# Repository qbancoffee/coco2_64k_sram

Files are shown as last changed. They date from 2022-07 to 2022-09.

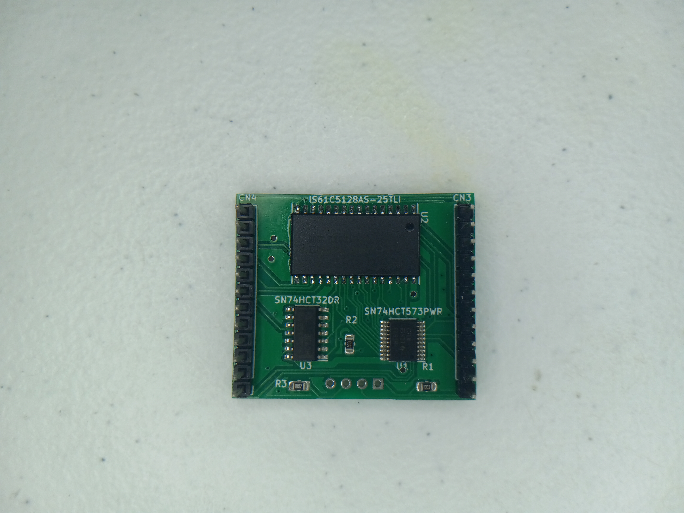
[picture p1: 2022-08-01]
images/board_bottom.jpg

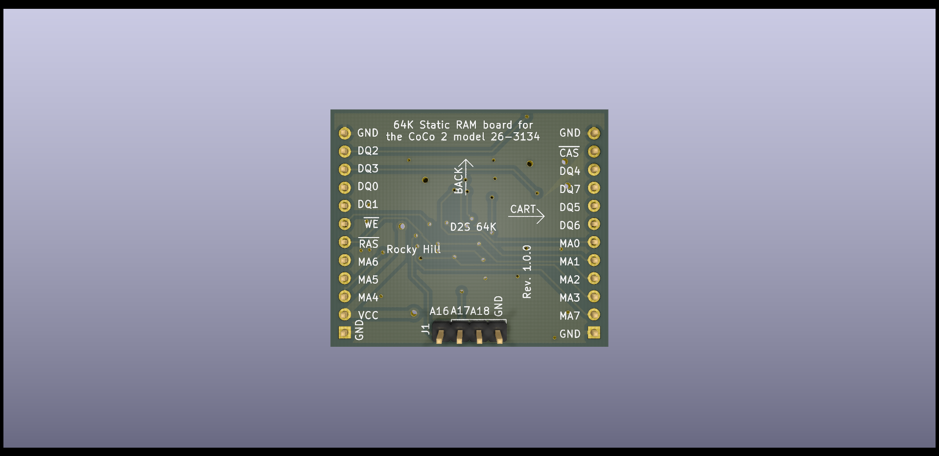
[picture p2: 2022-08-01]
images/board_top_rendered.png

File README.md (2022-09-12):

# coco2_64k_sram
Static RAM board for the Tandy Color Computer 2 model 26-3134

This KiCAD project includes the schematic and PCB design for a 64k static RAM board for the
Tandy Color Computer 2 model 26-3134. It is designed to plug into the expansion port.
There are two versions of the board in this repo, the main one which is the SMD version
and there is a through hole version under "coco2_3134_64k_static_ram_board_tht".

## Credits
The design for this board was inspired by the following.
- [Ciaran Ascomb's 512K static RAM board for the CoCo 3.](https://gitlab.com/sixxie/cc3-512k)
- [Jamaru's static RAM board for for the Commodore 64, based on Garrit4's design](https://github.com/jamarju/c64-sram)
- [Garrit4's SRAM board design.](https://www.lemon64.com/forum/viewtopic.php?p=773935#773935)

## Docs
- [Schematic](https://github.com/qbancoffee/coco2_64k_sram/blob/main/pdfs/schematic.pdf)
- [Rendered Image top](https://github.com/qbancoffee/coco2_64k_sram/blob/main/images/board_top_rendered.png)
- [Rendered Image bottom](https://github.com/qbancoffee/coco2_64k_sram/blob/main/images/board_bottom_rendered.png)
- [Board top](https://github.com/qbancoffee/coco2_64k_sram/blob/main/images/board_top.jpg)
- [Board bottom](https://github.com/qbancoffee/coco2_64k_sram/blob/main/images/board_bottom.jpg)
- [Board installed](https://github.com/qbancoffee/coco2_64k_sram/blob/main/images/board_installed.jpg)
- [Interactive BOM](https://htmlpreview.github.io/?https://github.com/qbancoffee/coco2_64k_sram/blob/main/bom/ibom.html)
- [Interactive BOM for the through hole version](https://htmlpreview.github.io/?https://github.com/qbancoffee/coco2_64k_sram/blob/main/bom/ibom_tht.html)
- [Bill Of Materials (BOM)](https://github.com/qbancoffee/coco2_64k_sram/blob/main/bom/bom.csv)
- [Bill Of Materials for the through hole version (BOM)](https://github.com/qbancoffee/coco2_64k_sram/blob/main/bom/bom_tht.csv)

## Videos
- [Installing the board in a CoCo 2](https://youtu.be/qNmRELRTp34)
- [Making a through hole version of the board](https://youtu.be/qkUWCKWGy-E)

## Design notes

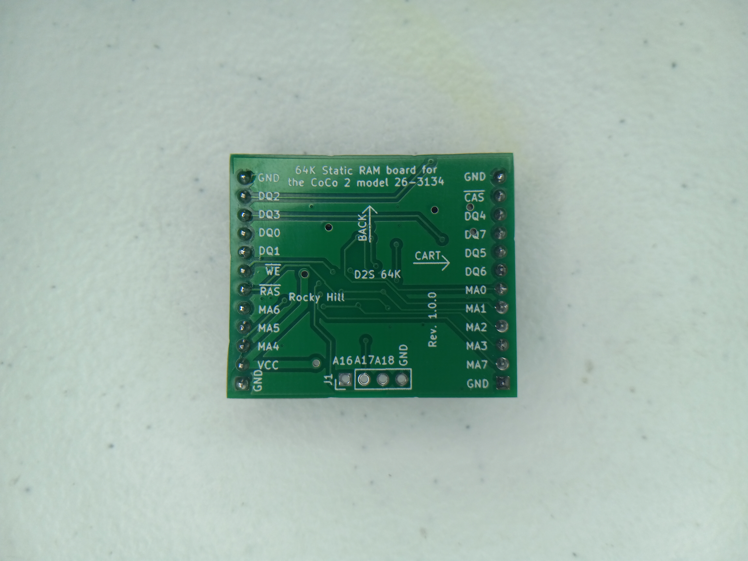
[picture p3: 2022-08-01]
images/board_top.jpg

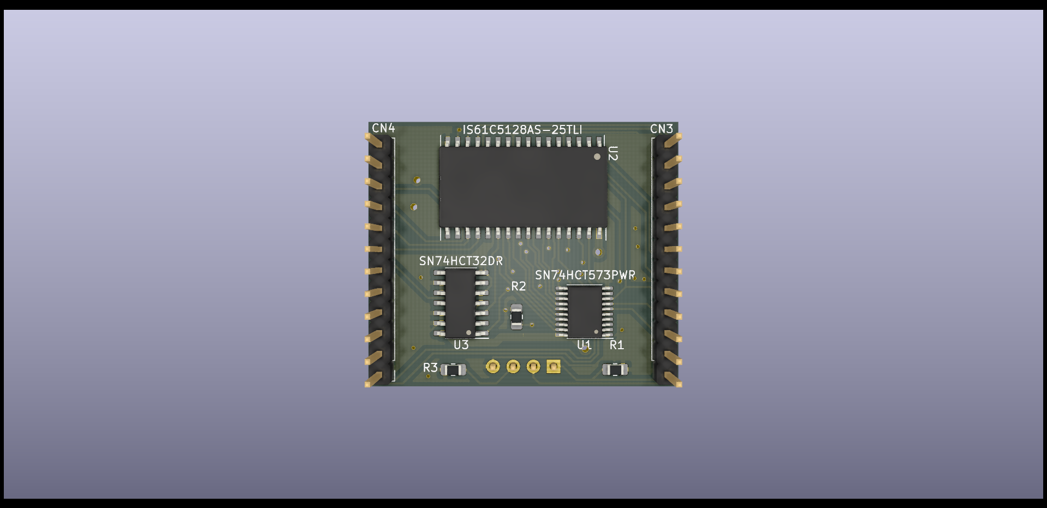
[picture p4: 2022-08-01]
images/board_bottom_rendered.png

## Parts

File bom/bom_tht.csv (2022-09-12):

Reference | Quantity | manufacturer part# | vendor | vendor part# | Value | Footprint | Datasheet
C1 C2 C3 | 3 | RDER71H104K0K1H03B | digikey | 490-8814-ND | .1uF | Capacitor_THT:C_Disc_D4.7mm_W2.5mm_P5.00mm | https://search.murata.co.jp/Ceramy/image/img/A01X/G101/ENG/RDE_X7R_250V-1kV_E.pdf
CN3 CN4 | 2 |  |  |  | Conn_01x12_Male | Connector_PinHeader_2.54mm:PinHeader_1x12_P2.54mm_Vertical | ~
U1 | 1 | SN74ALS573CN | digikey | 296-1502-5-ND | SN74ALS573CN | Package_DIP:DIP-20_W7.62mm_Socket_LongPads | https://www.ti.com/general/docs/suppproductinfo.tsp?distId=10
U2 | 1 | AS6C4008-55PIN | digikey | 1450-1178-5-ND | AS6C4008-55PIN | Package_DIP:DIP-32_W15.24mm | https://www.alliancememory.com/wp-content/uploads/pdf/AS6C4008.pdf
U3 | 1 | SN74ALS32N | digikey | 296-1495-5-ND | SN74ALS32N | Package_DIP:DIP-14_W7.62mm_Socket_LongPads | https://www.ti.com/lit/ds/sdas113b/sdas113b.pdf

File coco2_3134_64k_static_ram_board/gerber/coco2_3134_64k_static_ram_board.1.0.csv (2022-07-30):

Qty | Designator | Footprint | part# | Value
2 | CN3, CN4, | Connector_PinHeader_2.54mm:PinHeader_1x12_P2.54mm_Vertical | DNI | Conn_01x12_Male
1 | J1, | Connector_PinHeader_2.54mm:PinHeader_1x04_P2.54mm_Vertical | DNI | Conn_01x04_Female
3 | R1, R2, R3, | Resistor_SMD:R_0805_2012Metric_Pad1.20x1.40mm_HandSolder | C17414 | 10K
1 | U1, | Package_SO:TSSOP-20_4.4x6.5mm_P0.65mm | C141336 | SN74HCT573PWR
1 | U2, | Package_SO:TSOP-II-32_21.0x10.2mm_P1.27mm | DNI | IS61C5128AS-25TLI
1 | U3, | Package_SO:SOIC-14_3.9x8.7mm_P1.27mm | C6781 | SN74HCT32DR

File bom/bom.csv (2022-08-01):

Requested Quantity 1 | Part Number | Vendor | Manufacturer Part Number | Manufacturer Name | Description | Reference Designator
1 | 296-29253-1-ND | Digikey | SN74HCT573PWR | Texas Instruments | IC LATCH OCT TRANSP D 20TSSOP | U1
1 | 706-1059-ND | Digikey | IS61C5128AS-25TLI | ISSI, Integrated Silicon Solution Inc | IC SRAM 4MBIT PARALLEL 32TSOP II | U2
1 | 296-1614-5-ND | Digikey | SN74HCT32D | Texas Instruments | IC GATE OR 4CH 2-INP 14SOIC | U3
3 | 311-10.0KCRCT-ND | Digikey | RC0805FR-0710KL | YAGEO | RES 10K OHM 1% 1/8W 0805 | R1 R2 R3
1 | 732-5331-ND | Digikey | 61302411121 | Würth Elektronik | CONN HEADER VERT 24POS 2.54MM | CN3 CN4

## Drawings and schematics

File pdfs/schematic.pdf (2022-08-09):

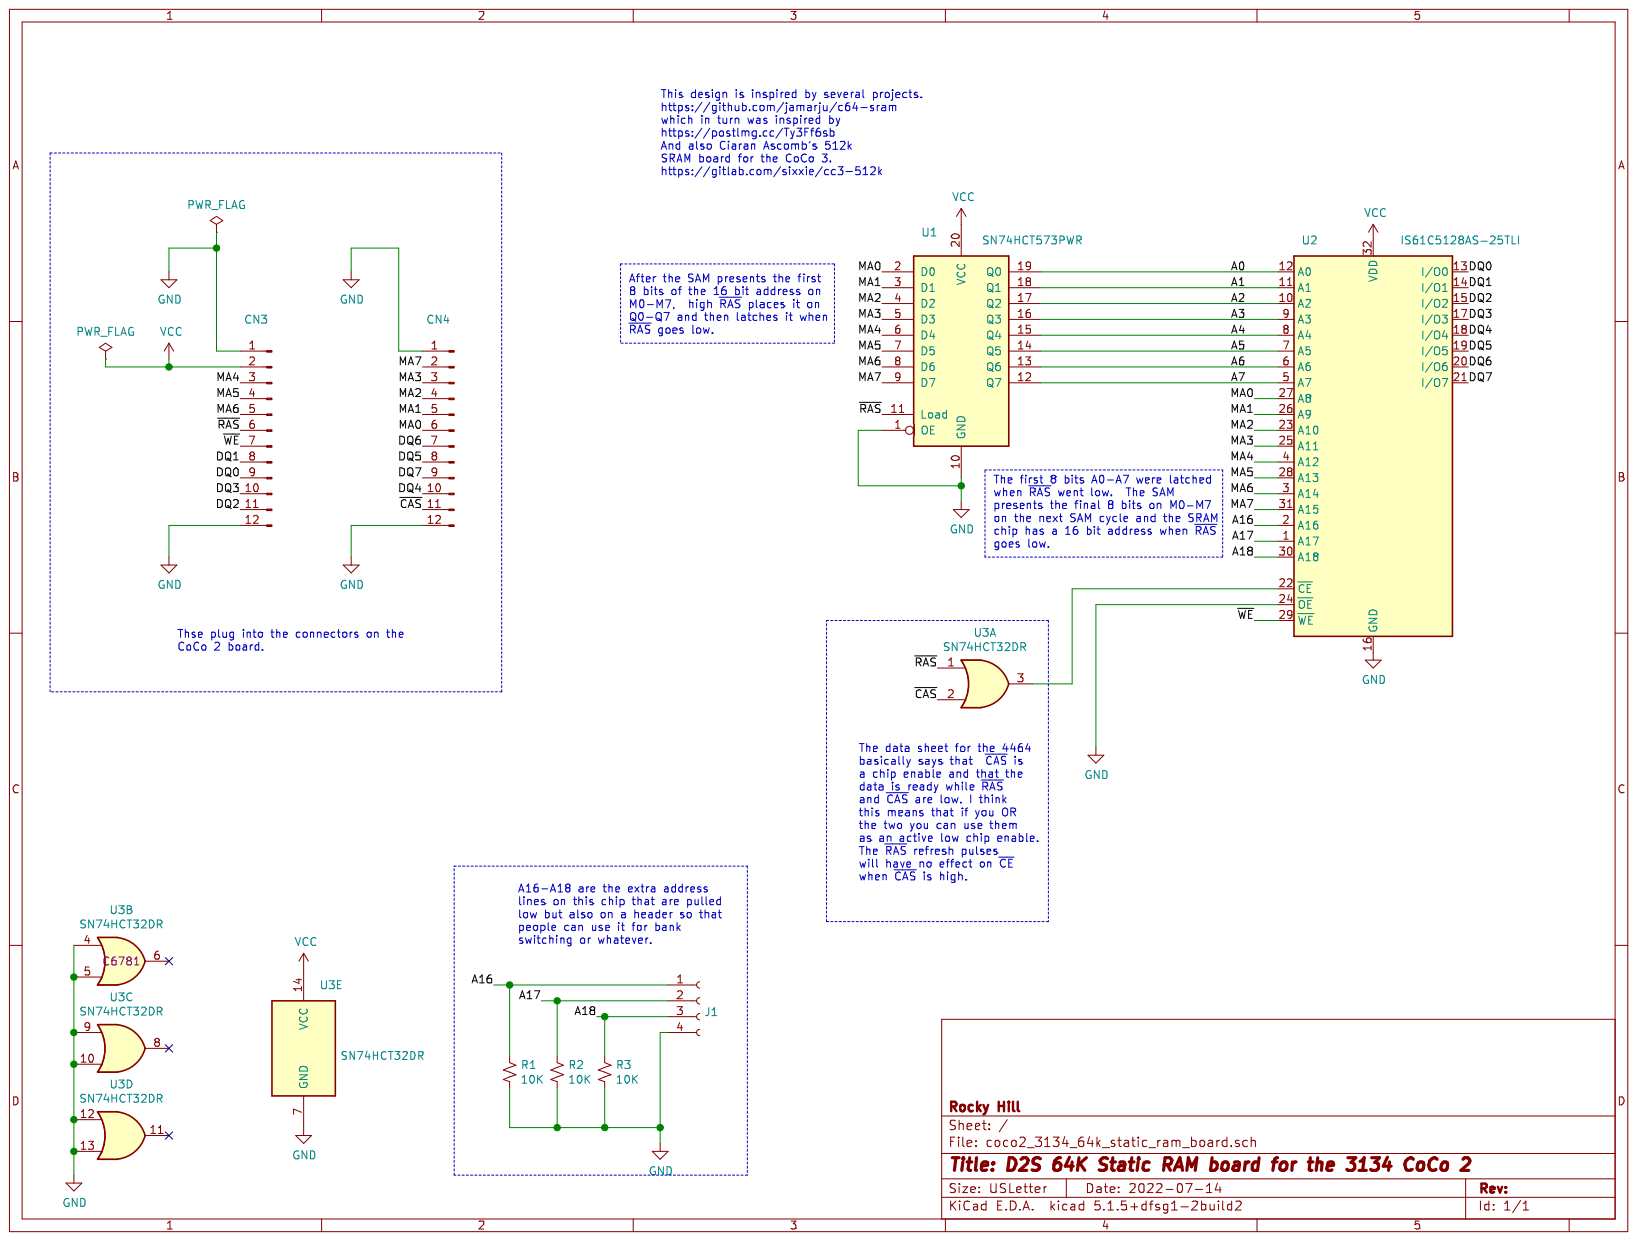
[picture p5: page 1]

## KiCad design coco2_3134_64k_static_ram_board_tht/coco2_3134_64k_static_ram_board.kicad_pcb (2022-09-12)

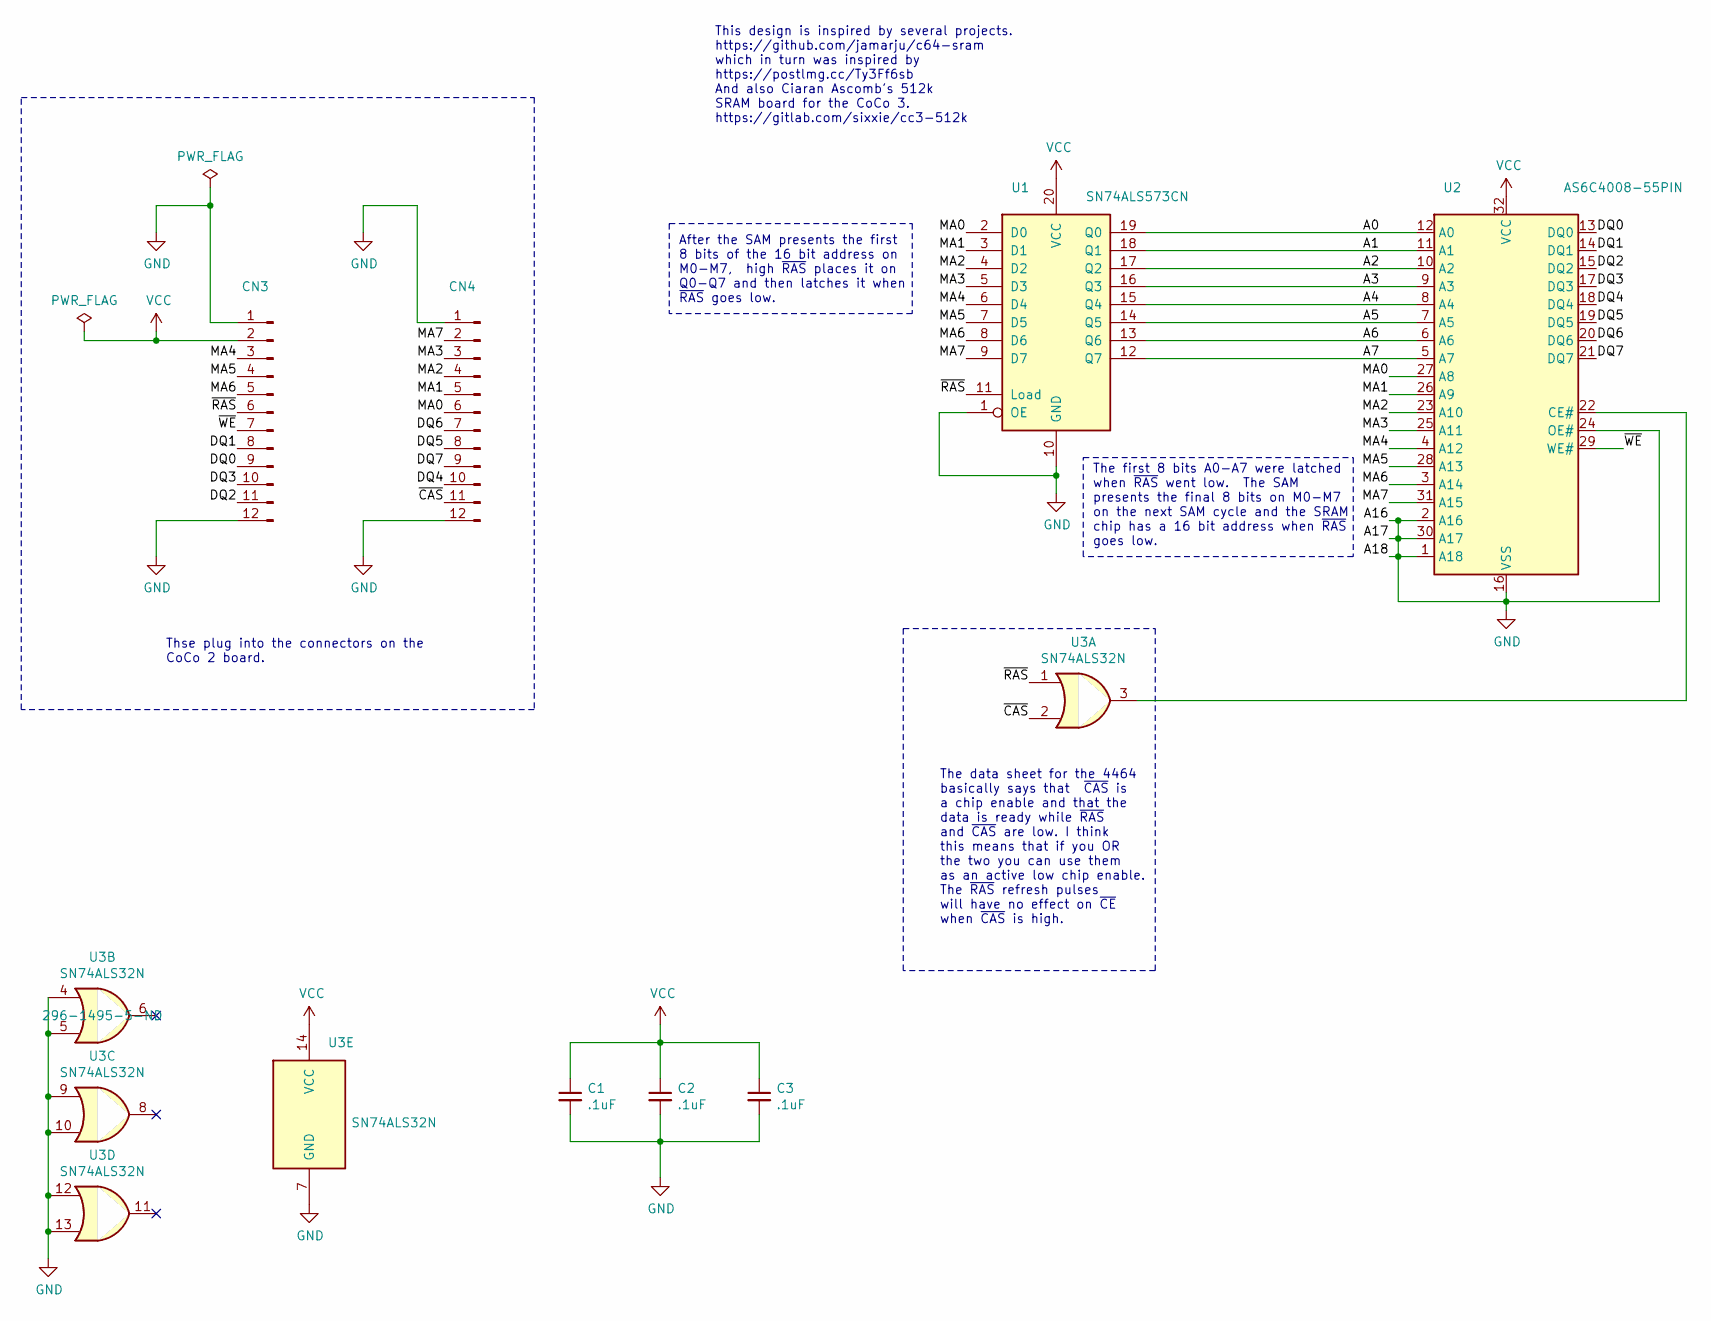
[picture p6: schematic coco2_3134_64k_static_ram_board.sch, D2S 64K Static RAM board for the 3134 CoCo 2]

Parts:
C1, C2, C3: .1uF; C_Disc_D4.7mm_W2.5mm_P5.00mm; manufacturer part# RDER71H104K0K1H03B
CN3, CN4: Conn_01x12_Male; PinHeader_1x12_P2.54mm_Vertical
U1: SN74ALS573CN; DIP-20_W7.62mm_Socket_LongPads; manufacturer part# SN74ALS573CN
U2: AS6C4008-55PIN; DIP-32_W15.24mm; manufacturer part# AS6C4008-55PIN
U3: SN74ALS32N; DIP-14_W7.62mm_Socket_LongPads; manufacturer part# SN74ALS32N

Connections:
/A0: U1.19 (Q0), U2.12 (A0)
/A1: U1.18 (Q1), U2.11 (A1)
/A2: U1.17 (Q2), U2.10 (A2)
/A3: U1.16 (Q3), U2.9 (A3)
/A4: U1.15 (Q4), U2.8 (A4)
/A5: U1.14 (Q5), U2.7 (A5)
/A6: U1.13 (Q6), U2.6 (A6)
/A7: U1.12 (Q7), U2.5 (A7)
/DQ0: CN3.9, U2.13 (DQ0)
/DQ1: CN3.8, U2.14 (DQ1)
/DQ2: CN3.11, U2.15 (DQ2)
/DQ3: CN3.10, U2.17 (DQ3)
/DQ4: CN4.10, U2.18 (DQ4)
/DQ5: CN4.8, U2.19 (DQ5)
/DQ6: CN4.7, U2.20 (DQ6)
/DQ7: CN4.9, U2.21 (DQ7)
/MA0: CN4.6, U1.2 (D0), U2.27 (A8)
/MA1: CN4.5, U1.3 (D1), U2.26 (A9)
/MA2: CN4.4, U1.4 (D2), U2.23 (A10)
/MA3: CN4.3, U1.5 (D3), U2.25 (A11)
/MA4: CN3.3, U1.6 (D4), U2.4 (A12)
/MA5: CN3.4, U1.7 (D5), U2.28 (A13)
/MA6: CN3.5, U1.8 (D6), U2.3 (A14)
/MA7: CN4.2, U1.9 (D7), U2.31 (A15)
/~CAS: CN4.11, U3.2
/~RAS: CN3.6, U1.11 (Load), U3.1
/~WE: CN3.7, U2.29 (WE#)
GND: C1.2, C2.2, C3.2, CN3.1, CN3.12, CN4.1, CN4.12, U1.1 (OE), U1.10 (GND), U2.1 (A18), U2.2 (A16), U2.16 (VSS), U2.24 (OE#), U2.30 (A17), U3.4, U3.5, U3.7 (GND), U3.9, U3.10, U3.12, U3.13
unnamed: U2.22 (CE#), U3.3
VCC: C1.1, C2.1, C3.1, CN3.2, U1.20 (VCC), U2.32 (VCC), U3.14 (VCC)

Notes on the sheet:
The data sheet for the 4464 basically says that ~CAS~ is a chip enable and that the data is ready while ~RAS~ and ~CAS~ are low. I think this means that if you OR the two you can use them as an active low chip enable. The ~RAS~ refresh pulses will have no effect on ~CE~ when ~CAS~ is high.
This design is inspired by several projects. https://github.com/jamarju/c64-sram which in turn was inspired by https://postlmg.cc/Ty3Ff6sb And also Ciaran Ascomb's 512k SRAM board for the CoCo 3. https://gitlab.com/sixxie/cc3-512k
Thse plug into the connectors on the CoCo 2 board.
After the SAM presents the first 8 bits of the 16 bit address on M0-M7, high ~RAS~ places it on Q0-Q7 and then latches it when ~RAS~ goes low.
The first 8 bits A0-A7 were latched when ~RAS~ went low. The SAM presents the final 8 bits on M0-M7 on the next SAM cycle and the SRAM chip has a 16 bit address when ~RAS~ goes low.

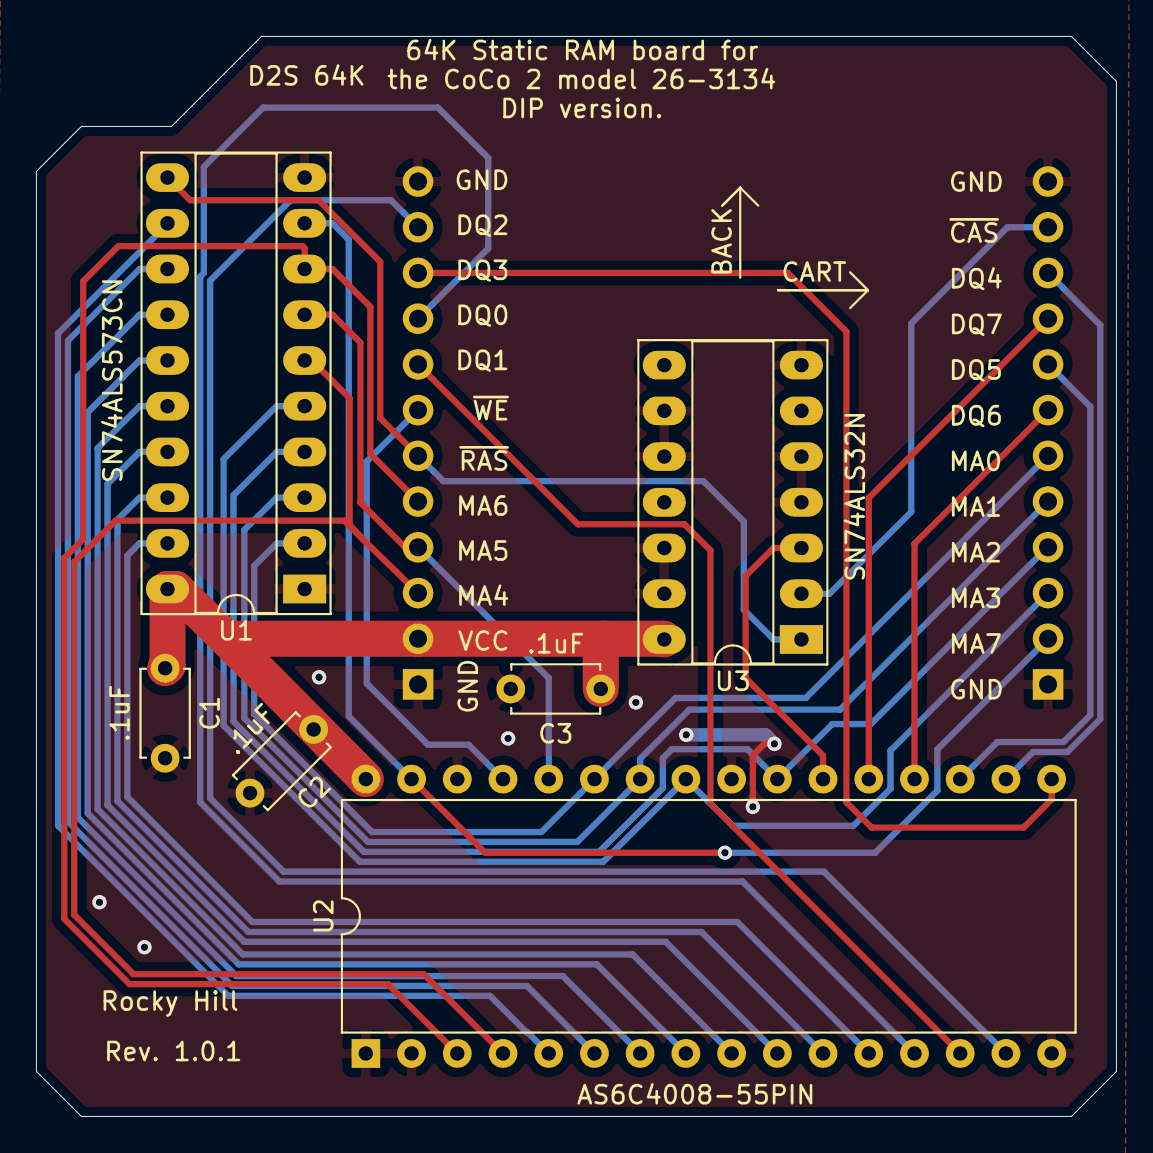
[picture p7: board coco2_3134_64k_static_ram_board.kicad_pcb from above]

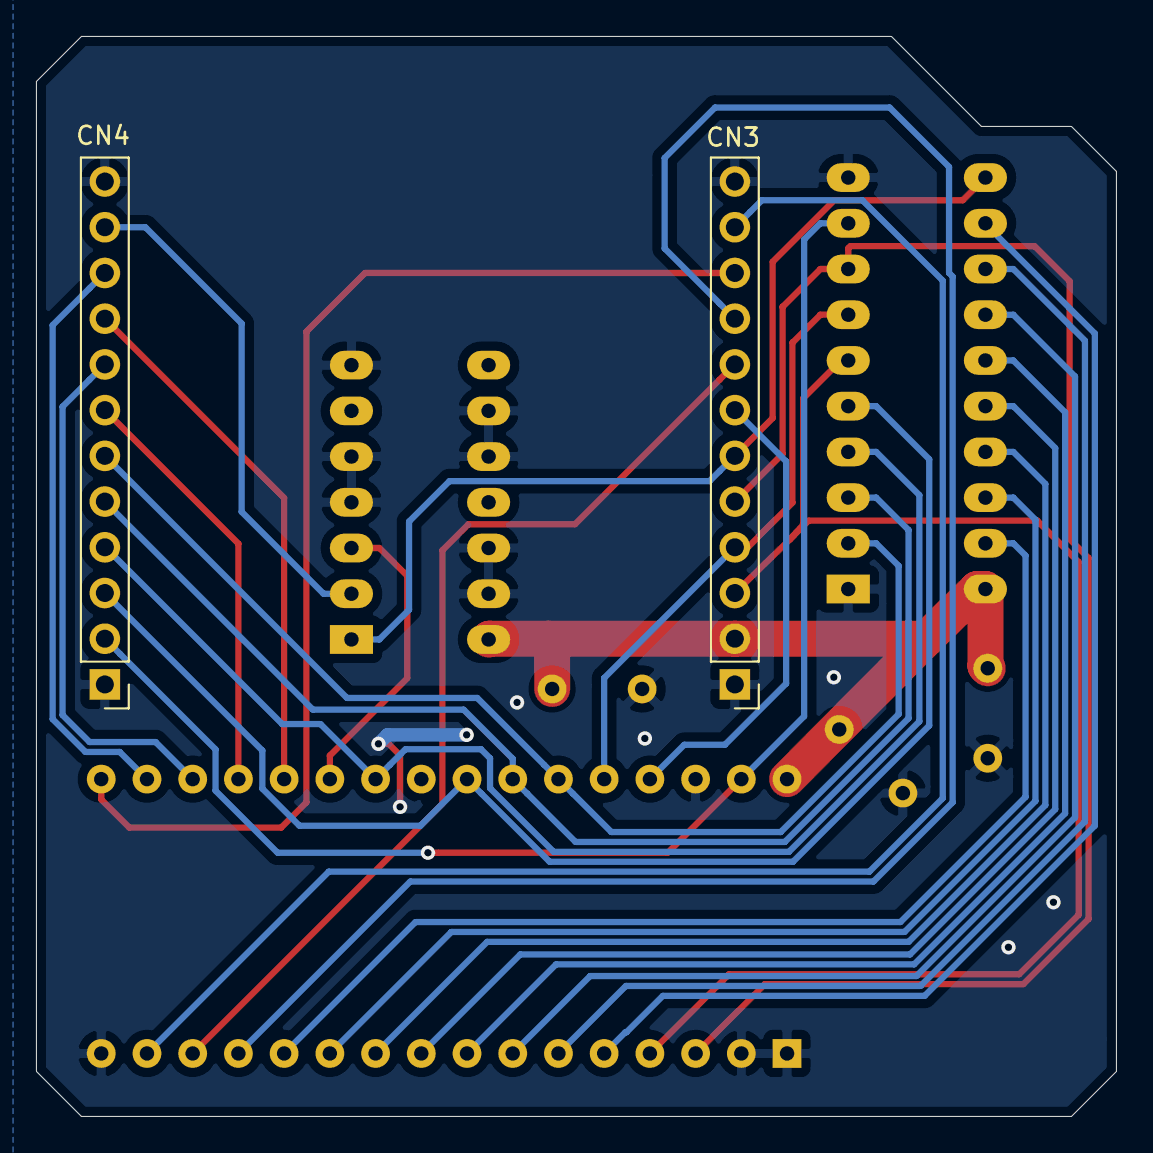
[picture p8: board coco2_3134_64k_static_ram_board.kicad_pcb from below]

Board: 2 copper layers, 60.0 x 60.0 mm, 8 parts (2 on the bottom side), 30 nets.

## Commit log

2022-08-01 added images and BOM
    [bom.csv, coco2_3134_64k_static_ram_board.sch]
2022-08-01 added missing part number
    [bom.csv]
2022-08-09 made corrections to descriptions on how the address is converted for use with the SRAM chip
    [coco2_3134_64k_static_ram_board.sch]
2022-09-12 added through hole version of the board.
    [bom_tht.csv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]
